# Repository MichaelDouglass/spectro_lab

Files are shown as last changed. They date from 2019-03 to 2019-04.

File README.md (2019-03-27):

# spectro_lab
This is a first run at a lab for college juniors and seniors in a bioinstrumentation course. The objective is to understand spectrophotometry.

For future reference and laser prints, I have decided to call this Project Pocket Photon. It may change, but that is what we are on now.

Project Pocket Photon uses a plywood laser cut box (file to cut in repository) to house the portable spectrophotometry unit. The light source is a white LED, the diffraction grating is a DVD substrate, and the sensor is a photoresitor.

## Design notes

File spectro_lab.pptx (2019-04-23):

## SpectroLab EBME 360

Shine on, forever.

Spr 2019

## Goals

- Understand how important light is and how awesome it is to gather information about molecules.
- Really understand how important light is.
- Use MATLAB to interface with Arduino.
  - We have released the C++ code, and if you are interested, definitely reach out to a TA for more info. We have found that teaching Arduino on the fly is like pushing you out of an airplane without telling you where the ripcord is. But, if you prefer to struggle with C++ also let us know in the reviews below. Don’t forget to like and subscribe.

## See the rainbow…

- There is no white wavelength of light.
- Rather, white is a combination of a lot of different light waves.
- We want to break white light down to its different wavelengths and then use that to see how our solution behaves.

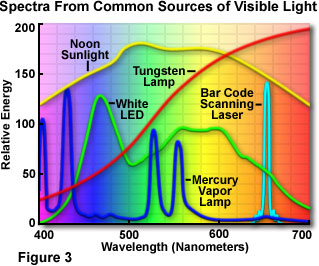
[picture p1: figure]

## Putting the “Photon” Together

- BOM
  - Laser Cut “Photon” Setup (What a clever name)
  - An extra bright LED (3.3 V from Arduino)
    - Select a resistor that limits the current to 20 mA
  - A photo resistor with amplification circuit (3.3 V from Arduino)
    - HEY! NOT 5 V! Use 3.3 V.
  - A stepper motor with a DVD “diffraction grating”
    - Stepper motor driver
    - Use the breadboard power regulator to get 5 V from the 9 V battery
  - 2 Cuvettes
  - Arduino
  - Photon_speak.ino
  - A breadboard or two
  - A positive outlook on learning

## Circuit Diagram

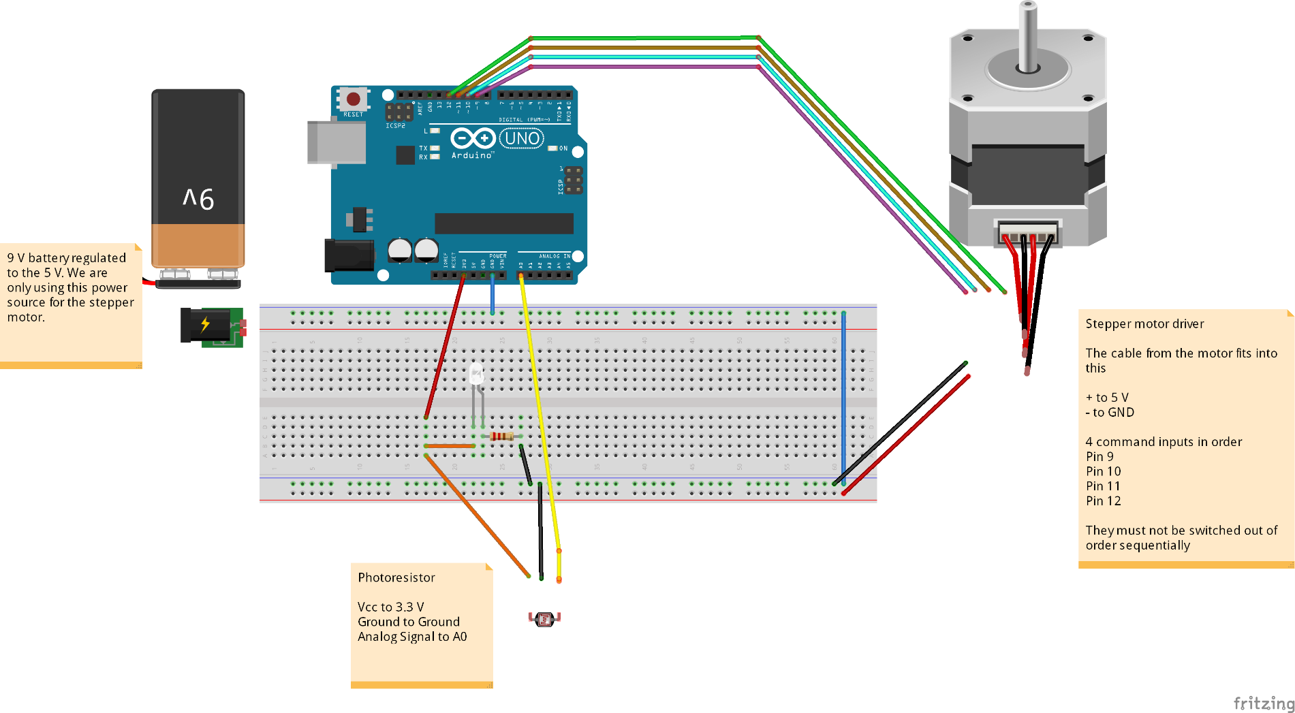
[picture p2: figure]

Power Regulator fits right on breadboard. One side is 3.3 V and the other is 5 V. Use the 5 V rails for the stepper motor.

A0

VCC

GND

## Actually Seeing the Rainbow

See Rainbow Here

- Use the LED to shine light onto the DVD. Spin it around until you see the rainbow on the other side of the photon.

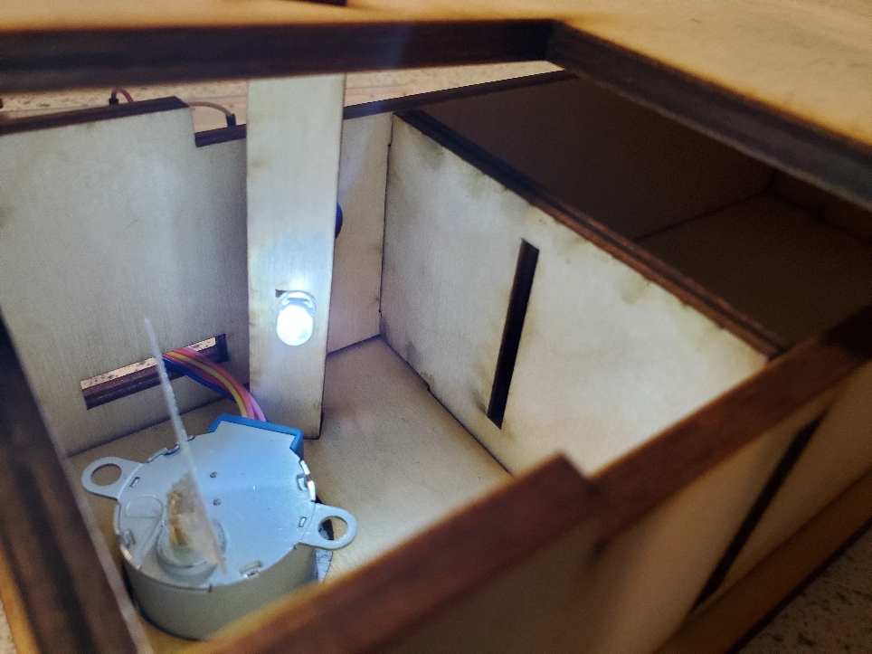
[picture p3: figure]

## Measuring ROYGBIV

- As we take steps with the stepper motor, we can isolate certain wavelengths that the detector sees. The setup can definitely do this.

The Spectrum Moves with the stepper motor.

And if you view this slide in presentation mode, the spectrum moves with a click

Measure Here

## Using MATLAB to send and receive requests

- We will treat our Arduino like an instrument. Some of you may have used ASCII commands to “talk” to oscilloscopes and function generators before. It is extremely useful and can automate data collection like CRAZY!
- The C++ that you uploaded to your Arduino (photon_speak.ino) acts as a way to create an instrument.
  - Make sure you uploaded the code
- Start Matlab alongside this powerpoint. Use the student skeleton file on canvas.
- Open up a Serial Port using the following commands
ardy = serial(‘COMxy’, ‘BaudRate’, 115200)
fopen(ardy)
fscanf(ardy)
- ‘COM10’ will be different based on the port where your Arduino is. Use the tools tab on the Arduino IDE as an easy way to find your port.

## Sending and Receiving

- What we want to do is “speak” to the Arduino
- Use the following commands to do that
fprintf(ardy, “*IDN?”)
fscanf(ardy)
- If fscanf returns a quirky message, then you’ve succeeded.
- IMPORTANT:
  - To close your instrument use the following sequence:
fclose(ardy)
delete(ardy)
clear ardy
  - You may forget to close your instrument. MATLAB makes it relatively easy to mend this mistake, so if you get an error opening your ardy through serial, use instrreset to start over.

## Your Commands

- You can send certain commands to the Arduino. Remember to always do an fscanf after an fprintf. If you’re clever, there is a function that combines the two, but if you’re just learning stick to the basics.
- “*IDN?”
  - The Arduino will respond with its identity
- “:STP:MOV N”
  - The Stepper Motor will move N amount of steps
- “:STP:SET N”
  - N is 0 or 1 corresponding to CW and CCW rotation.
- “:MEA?”
  - Return the output of the photoresistor.
    - Remember this is in bits (0-1023)

## Gather the spectrum of spinach

- Now you should write some code to explore the spectrum of chlorophyll
- There’s a lot of tips in the Matlab code

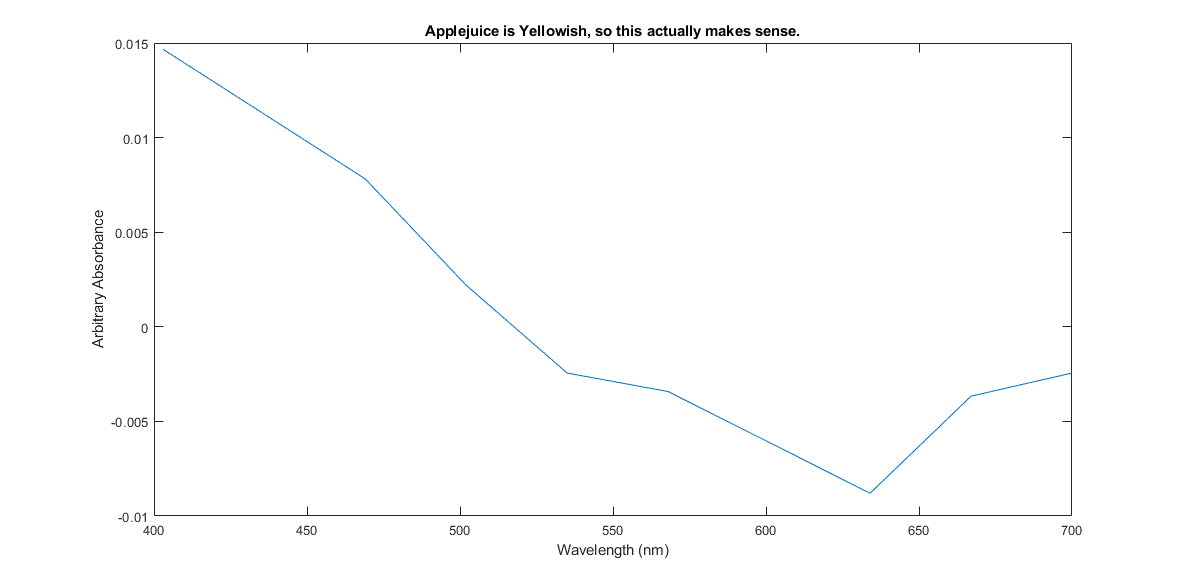
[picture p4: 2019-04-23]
applejuice.png

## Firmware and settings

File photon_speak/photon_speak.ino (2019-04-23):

#include "ardy.h"
#include "lever.h"
#include "commands.h"

// pointer for commands
char* options;

// chars read from serial line
int charsRead;

// serial message stored here
char msg[50];

// main interface with our various functions
Ardy ardy;

// setup
void setup() {
  init_commands(&cmds);
  Serial.begin(115200);
  ardy.init_lever();
  ardy.init_stepper();
  delay(500);
  Serial.println("Ready!");
}


void loop() {
  // check that we have things to read
  if (Serial.available())
  {
    // read from serial port
    charsRead = Serial.readBytesUntil('\n', msg, sizeof(msg) - 1);

    // make c string
    msg[charsRead] = '\0';

    // parse and set commands up
    set_commands(&cmds, msg);
  }

}

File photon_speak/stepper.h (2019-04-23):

#ifndef STEP_H
#define STEP_H

class Stepper
{
  private:

    int pin1;
    int pin2;
    int pin3;
    int pin4;

    int step_number;

    bool direction;

  public:
    Stepper()
    {
      this->pin1 = 9;
      this->pin2 = 10;
      this->pin3 = 11;
      this->pin4 = 12;
      this->direction = 1;
    };
    ~Stepper(){};

    void init_step()
    {
      pinMode(this->pin1, OUTPUT);
      pinMode(this->pin2, OUTPUT);
      pinMode(this->pin3, OUTPUT);
      pinMode(this->pin4, OUTPUT);
    }

    bool get_dir()
    {
      return this->direction;
    }

    void set_dir(bool direction)
    {
      this->direction = direction;
    }

    void one_step()
    {
      if(this->direction)
      {
        switch(this->step_number)
        {
          case 0:
          digitalWrite(this->pin1, HIGH);
          digitalWrite(this->pin2, LOW);
          digitalWrite(this->pin3, LOW);
          digitalWrite(this->pin4, LOW);
          break;
          case 1:
          digitalWrite(this->pin1, LOW);
          digitalWrite(this->pin2, HIGH);
          digitalWrite(this->pin3, LOW);
          digitalWrite(this->pin4, LOW);
          break;
          case 2:
          digitalWrite(this->pin1, LOW);
          digitalWrite(this->pin2, LOW);
          digitalWrite(this->pin3, HIGH);
          digitalWrite(this->pin4, LOW);
          break;
          case 3:
          digitalWrite(this->pin1, LOW);
          digitalWrite(this->pin2, LOW);
          digitalWrite(this->pin3, LOW);
          digitalWrite(this->pin4, HIGH);
          break;
        }
      }
      else
      {
        switch(this->step_number)
        {
          case 0:
          digitalWrite(this->pin1, LOW);
          digitalWrite(this->pin2, LOW);
          digitalWrite(this->pin3, LOW);
          digitalWrite(this->pin4, HIGH);
          break;
          case 1:
          digitalWrite(this->pin1, LOW);
          digitalWrite(this->pin2, LOW);
          digitalWrite(this->pin3, HIGH);
          digitalWrite(this->pin4, LOW);
          break;
          case 2:
          digitalWrite(this->pin1, LOW);
          digitalWrite(this->pin2, HIGH);
          digitalWrite(this->pin3, LOW);
          digitalWrite(this->pin4, LOW);
          break;
          case 3:
          digitalWrite(this->pin1, HIGH);
          digitalWrite(this->pin2, LOW);
          digitalWrite(this->pin3, LOW);
          digitalWrite(this->pin4, LOW);
          break;
        }
      }
      this->step_number++;
      if (this->step_number>3)
      {
        this->step_number=0;
      }
    }

    void take_steps(int step_nums)
    {
      for (int i = 1; i < step_nums; i++ )
      {
        one_step();
        delay(2);
      }
    }
};

#endif

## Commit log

2019-03-27 Uploads Laser Cutter blueprints for Spectr_Lab ver 1 box
2019-03-27 Initializes necessary code for servo actuation with SCPI syntax
2019-04-03 Uploads latest version of laser cut box
2019-04-23 Updates box to ver 1.5 and adds teaching files.
    [photon.fzz]
